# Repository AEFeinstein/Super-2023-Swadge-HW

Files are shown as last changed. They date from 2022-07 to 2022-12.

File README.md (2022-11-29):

# Super Magfest 2023 Swadge Hardware

## Welcome

This is the hardware repository for the Super Magfest 2022 Swadge.

The corresponding firmware repository for the Super Magfest 2023 Swadge [can be found here](https://github.com/AEFeinstein/Super-2023-Swadge-FW).

If you have any questions, feel free to create a Github ticket or email us at circuitboards@magfest.org.

## Render
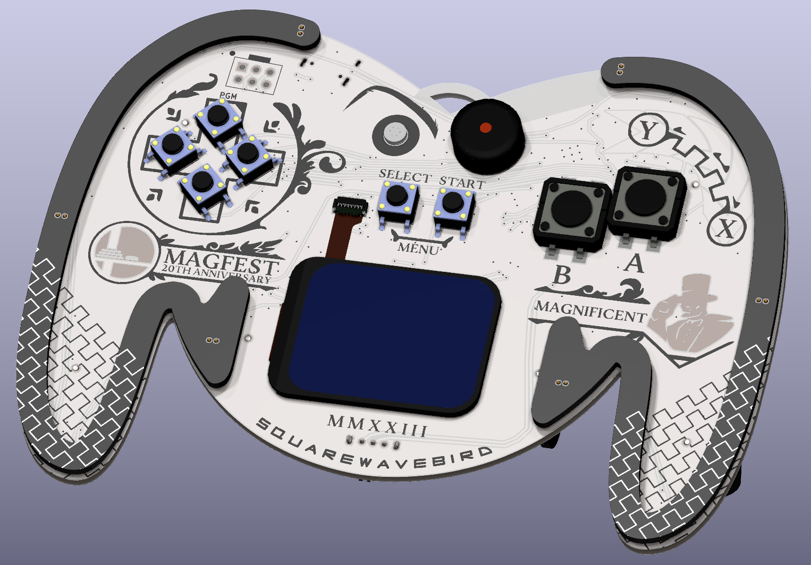
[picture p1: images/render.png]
Render


## Schematic

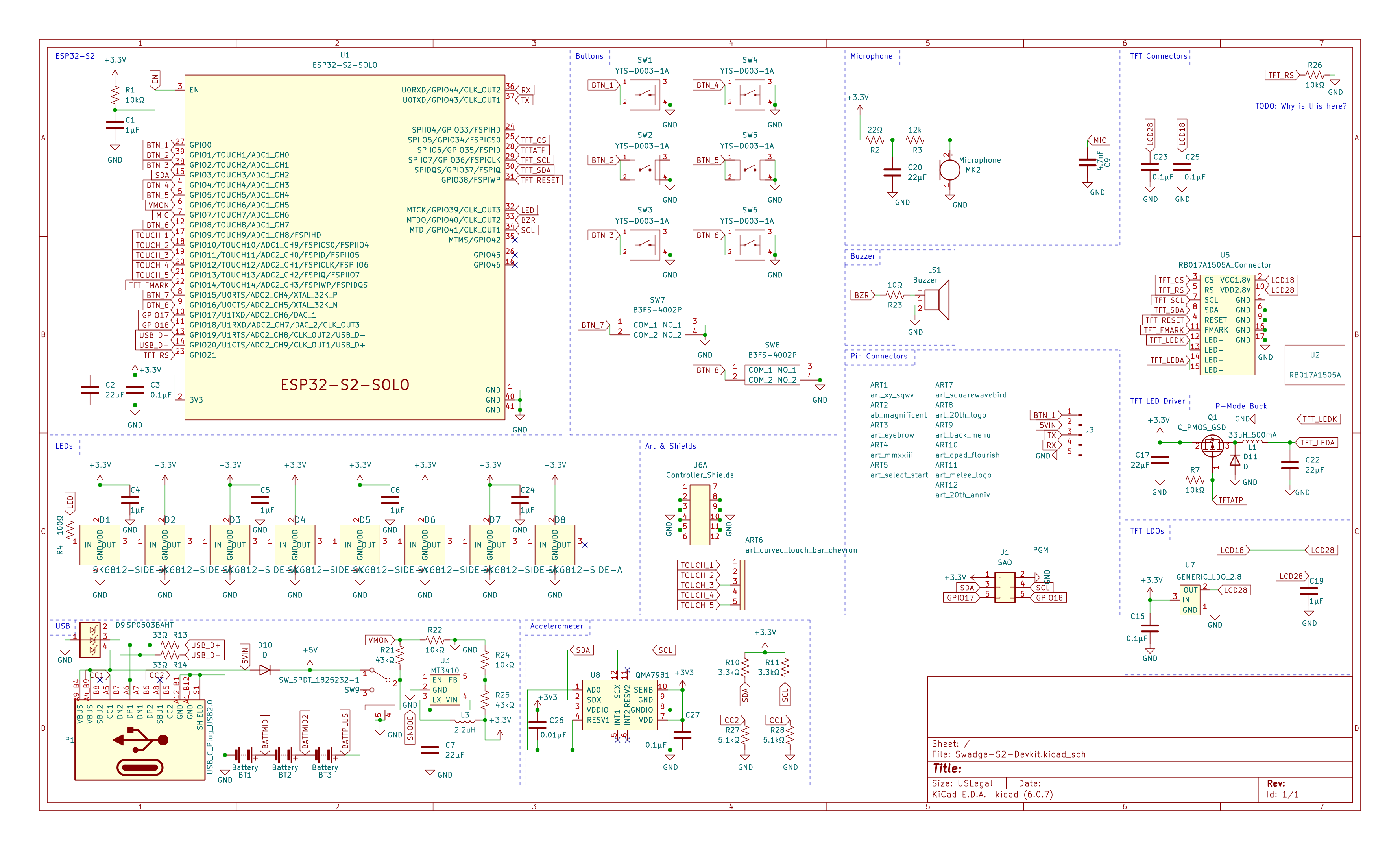
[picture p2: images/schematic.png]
Schematic


## Directories

### `art`
This directory has the SVGs used to generate the KiCad files. The SVGs are drawn in [Inkscape](https://inkscape.org/) and exported with [Svg2Shenzhen](https://github.com/badgeek/svg2shenzhen)
### `3D-Print`
This directory has the 3D print files for the Swadge "Eggshell". 
### `SAOs/SAO1`
This directory has the design files for a Simple Add On shaped like Lil'B
### `shield`
This directory has the KiCad project for the PCB shield which protects the LEDs. 
### `shield_l`
This directory has the KiCad project for a test left-side shield which protects the LEDs. It was never manufacturered.
### `shield_r`
This directory has the KiCad project for a test right-side shield which protects the LEDs. It was never manufacturered.
### `Swadge-Parts`
This directory is a git submodule which has all the parts, footprints, and 3D models used in this project.
### `Swadge-S2-Devkit`
This directory has the KiCad project for the main Swadge PCB. It's not really a devkit anymore, but it started out as one!

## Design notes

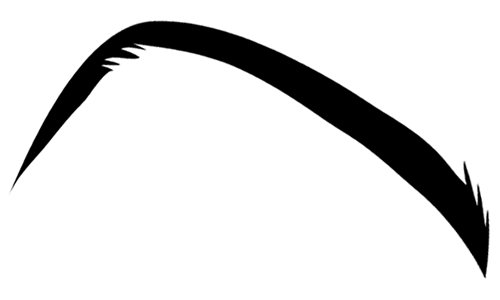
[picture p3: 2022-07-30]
art/Eyebrow.png

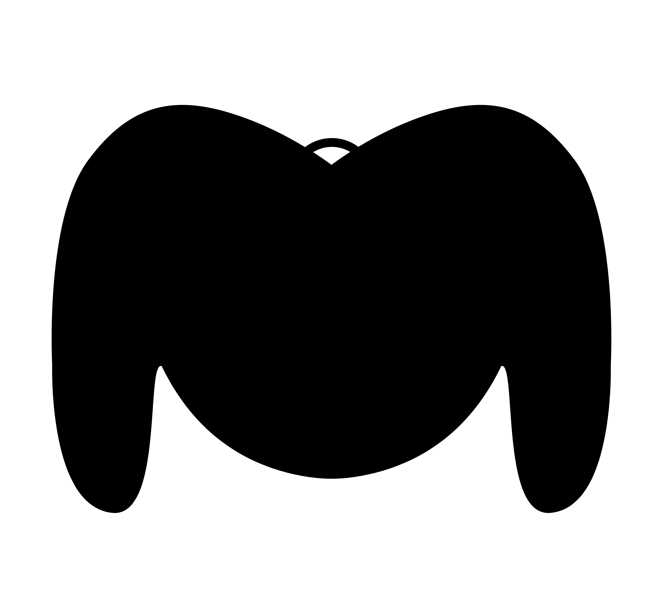
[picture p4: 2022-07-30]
art/Controller_Shape.png

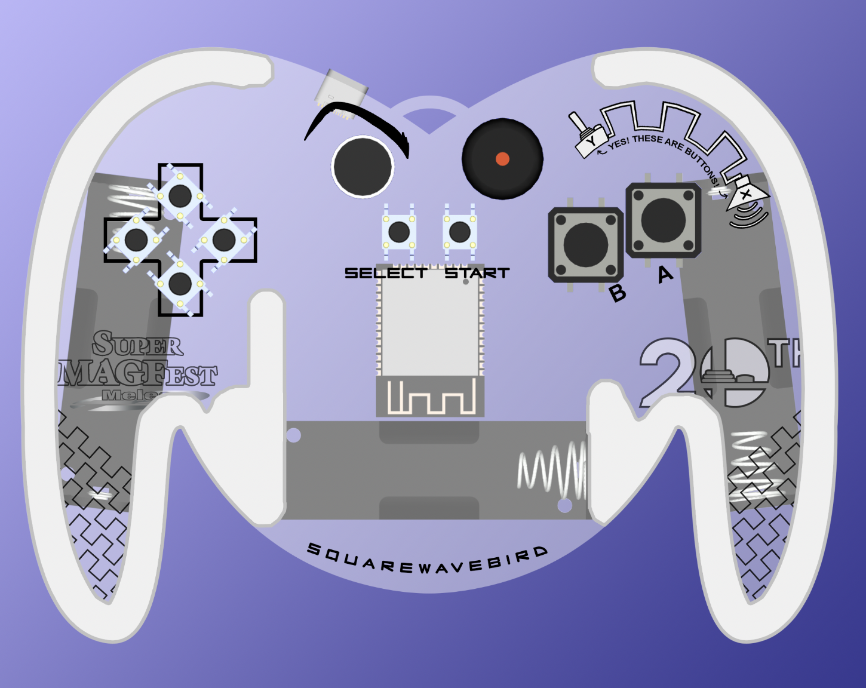
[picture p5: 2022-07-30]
art/_Dac_s Raster.png

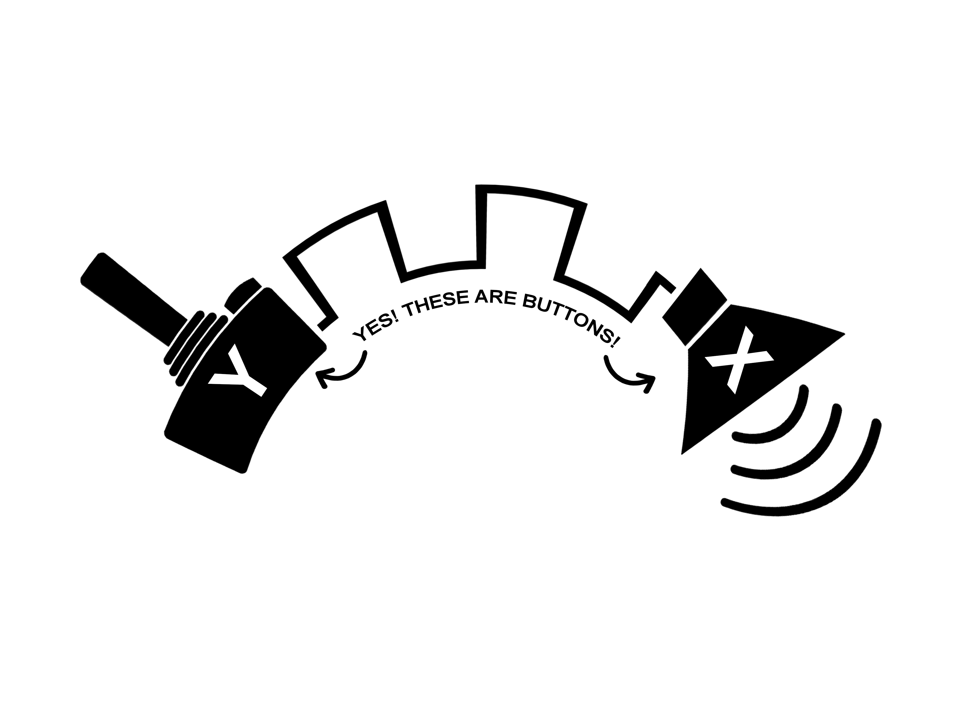
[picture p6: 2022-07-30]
art/XY_Buttons.png

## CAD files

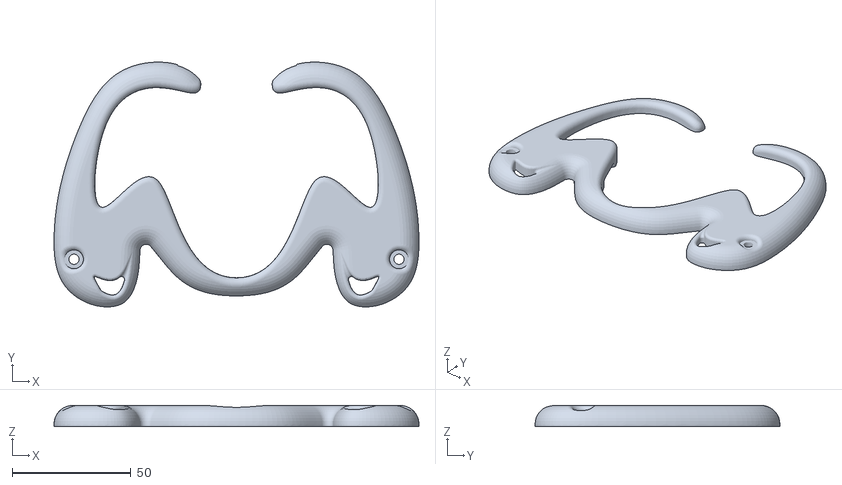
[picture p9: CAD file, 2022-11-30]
3D-Print/FDM/Eggshell_front_FDM.STL
153.4 x 102.9 x 8.89

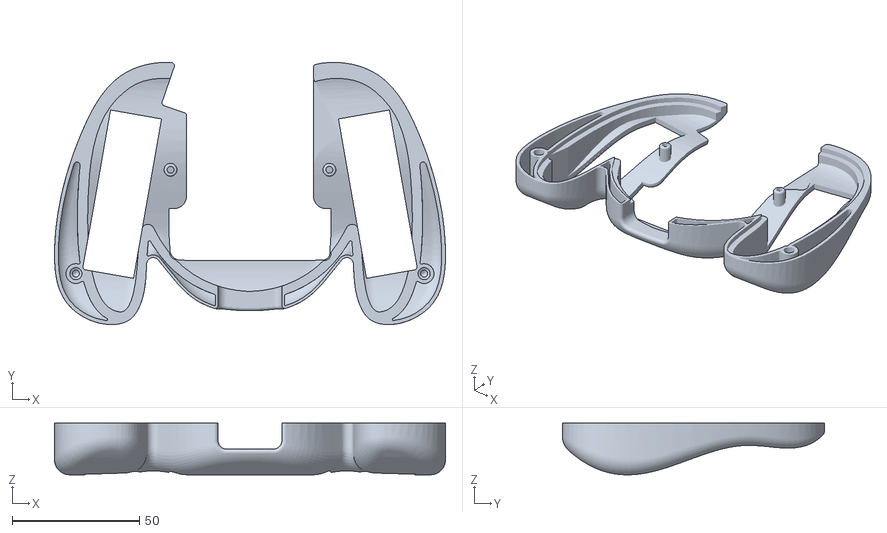
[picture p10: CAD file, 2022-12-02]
3D-Print/SLA/Eggshell_back_SLA.STL
153.4 x 102.9 x 20.3

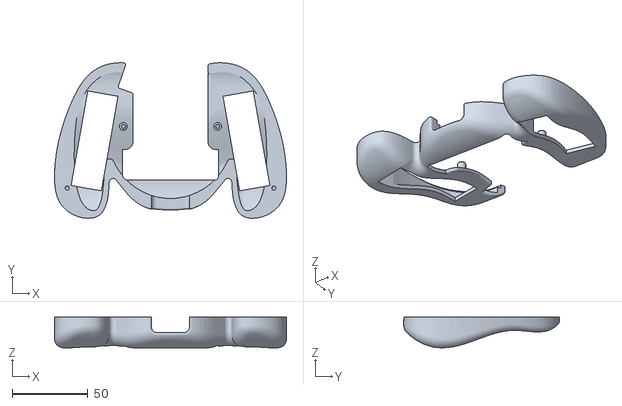
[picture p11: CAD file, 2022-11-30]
3D-Print/FDM/Eggshell_back_FDM.STL
153.4 x 102.9 x 20.3

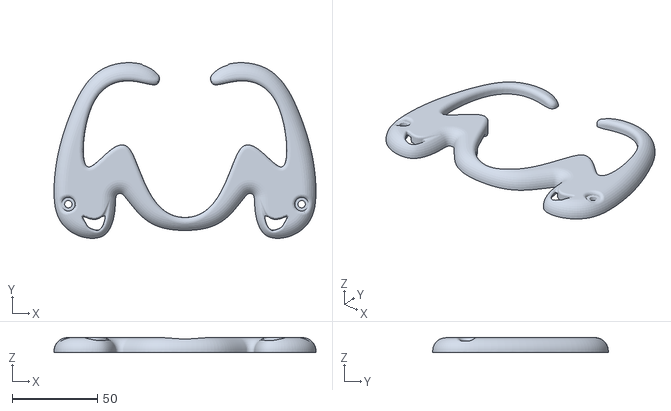
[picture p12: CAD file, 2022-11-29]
3D-Print/SLA/Eggshell_front_SLA.STL
153.4 x 102.9 x 8.69

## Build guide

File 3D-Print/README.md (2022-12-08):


<!--
*** Thanks for checking out the Best-README-Template. If you have a suggestion
*** that would make this better, please fork the repo and create a pull request
*** or simply open an issue with the tag "enhancement".
*** Don't forget to give the project a star!
*** Thanks again! Now go create something AMAZING! :D
-->

<!-- PROJECT SHIELDS -->
<!--
*** I'm using markdown "reference style" links for readability.
*** Reference links are enclosed in brackets [ ] instead of parentheses ( ).
*** See the bottom of this document for the declaration of the reference variables
*** for contributors-url, forks-url, etc. This is an optional, concise syntax you may use.
*** https://www.markdownguide.org/basic-syntax/#reference-style-links
-->

<!-- PROJECT LOGO -->
<br />
   
  <h1 align="center">Project Eggshell</h1>

  <p align="center">
    An ergonomic case for the 2023 Swadge
</p>

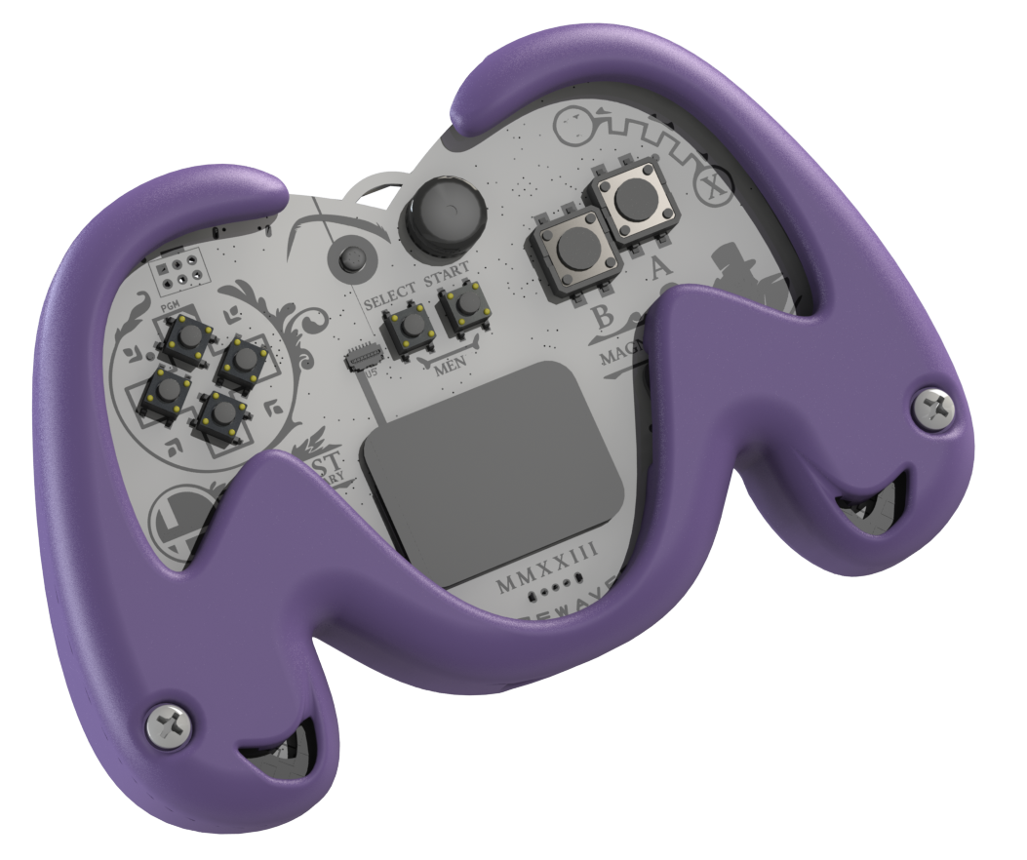
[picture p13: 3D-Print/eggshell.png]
Eggshell Render


### Built With
<br />

* [SOLIDWORKS 2020](https://www.solidworks.com) 

<p align="right">(<a href="#top">back to top</a>)</p>

<!-- GETTING STARTED -->
## Getting Started
<br />

Identify which type of printing technology you’d like to use to replicate your Swadge eggshell and use the respective files for that folder. It’s sincerely not recommended to use SLA files for FDM printers, though you could go the other way with significant resin use. This print has not been tested with SLS. 
<br />

### Materials

Materials required vary based on your printing method.

The materials used for the Eggshells produced for Super MAGFest 2023 are provided at the links below:

* <a href="https://www.amazon.com/Polymaker-Filament-1-75mm-Resistant-Cardboard/dp/B09DKQ7W32"> Purple ABS </a>

* <a href="https://www.amazon.com/dp/B08SQTR1FV">ClearPurple Resin</a> 

You’ll also need:

An FDM 3D printer capable of printing ABS filament with a minimum build volume of 150mm x 55mm x 20mm. Each piece was printed grip side UP and laid flat on the build plate. The eggshell was designed to minimize excess support structure. 15% infill should be plenty.

OR

An SLA printer capable of printing clear UV resin with a minimum build volume of 150mm x 55mm x 20mm. This has been tested on an Anycubic Photon Mono X for SLA prints with the following settings:

* Burn in layers: 6
* Burn in time: 35s
* Layer time: 3.2s
* UV power: 100%

Each side of the eggshell was printed individually at a 45deg angle based on True Elite Geek’s formula for resin printing. The grip surfaces were the supported side and gently sanded with 150 grit sandpaper post-printing, and then clear coated for finish.

OR

<p align="left">Money to spend at www.HUBS.com or www.shapeways.com to outsource prints.</p>

### Assembly

FDM and SLA prints are assembled differently. IF you are using a tappable resin such as Siraya Tech Build, you may be able to use the FDM mounting hardware. YMMV.

FDM Fasteners:

Any #6 x 5/8" self tapping screw. The eggshells were delivered at MAGFest 2023 with these screws: 
* Screws: https://www.mcmaster.com/92470A150/

SLA Fasteners:

The clear purple resin is not tappable. Use a press fit insert and a 6-32 x 1/2" screw instead. The eggshells were delivered at MAGFest 2023 with these fasteners:
* Threaded inserts: https://www.mcmaster.com/92395A113/
* Screws: https://www.mcmaster.com/91772A146/
 
<p align="right">(<a href="#top">back to top</a>)</p>

<!-- CONTRIBUTING -->
## Contributing

Contributions are what make the open-source community such an amazing place to learn, inspire, and create. Any contributions you make are **greatly appreciated**.

If you have a suggestion that would make this better, please fork the repo and create a pull request. You can also simply open an issue with the tag "enhancement".
Don't forget to give the project a star! Thanks again!

1. Fork the Project
2. Create your Feature Branch (`git checkout -b feature/AmazingFeature`)
3. Commit your Changes (`git commit -m 'Add some AmazingFeature'`)
4. Push to the Branch (`git push origin feature/AmazingFeature`)
5. Open a Pull Request

<p align="right">(<a href="#top">back to top</a>)</p>

<!-- LICENSE -->
## License

<p xmlns:cc="http://creativecommons.org/ns#" xmlns:dct="http://purl.org/dc/terms/"><a property="dct:title" rel="cc:attributionURL" href="https://github.com/AEFeinstein/Super-2023-Swadge-HW/tree/main/3D-Print">Swadge Eggshell</a> by <a rel="cc:attributionURL dct:creator" property="cc:attributionName" href="https://github.com/emilyanthony4244">Emily Anthony</a> is licensed under <a href="http://creativecommons.org/licenses/by-nc-sa/4.0/?ref=chooser-v1" target="_blank" rel="license noopener noreferrer" style="display:inline-block;">CC BY-NC-SA 4.0</a></p>

<!-- CONTACT -->
## Contact

Emily Anthony - [@thelegendofemily](https://instagram.com/thelegendofemily) 

Justin Gohlke –
[@justintroubleagain]( https://www.instagram.com/justintroubleagain/)

Project Link: https://github.com/AEFeinstein/Super-2023-Swadge-HW/

<p align="right">(<a href="#top">back to top</a>)</p>

<!-- ACKNOWLEDGMENTS -->
## Acknowledgments

* Justin Gohlke aka Eggman for being the mad scientist and dedicated printer for this project
* The Swadge team for idea generation, continuous feedback, and general tolerance for Justin and Emily to go buckwild
* MAGFest volunteers and employees for their overwhelming support and willingness to help push this side project
* [OthNealDrew’s Readme template]( https://github.com/othneildrew/Best-README-Template)

<p align="right">(<a href="#top">back to top</a>)</p>

<!-- MARKDOWN LINKS & IMAGES -->
<!-- https://www.markdownguide.org/basic-syntax/#reference-style-links -->
[contributors-shield]: https://img.shields.io/github/contributors/emilyanthony4244/Sheikah_Slate.svg?style=for-the-badge
[contributors-url]: 
https://github.com/AEFeinstein/Super-2023-Swadge-HW/graphs/contributors
[linkedin-shield]: https://img.shields.io/badge/-LinkedIn-black.svg?style=for-the-badge&logo=linkedin&colorB=555
[linkedin-url]: https://linkedin.com/in/emilyanthony

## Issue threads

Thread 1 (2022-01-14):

Validate Schematic

AEFeinstein, 2022-01-14:
Blocks to validate:
- [x] ESP32-S2
- [x] Buttons
- [x] Microphone
- [x] Speaker
- [x] Buzzer
- [x] TFT Display
- [x] LEDs
- [x] Vibration Motor
- [x] Edge Connector
- [x] Pin Headers
- [x] Accelerometer
- [x] USB
- [x] Touch Sensor

Closed 2022-09-02.

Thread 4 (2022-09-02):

Prototype Feedback

AEFeinstein, 2022-09-02:
# Silkscreen
 - [x] Replace chevron silkscreen with X/Y silkscreen
 - [x] Add silkscreen for power switch sides
 - [x] Add URL silkscreen "swadge.com/super2023/"
 - [x] Add e-mail silkscreen circuitboards@magfest.org
 - [x] Add version silkscreen (1.0.1)
 - [x] Add A and B button silkscreen
 - [x] Add silkscreen dot or marking or something for UP on the D-Pad to indicate "programming mode button"
 - [x] "Yes these are buttons"

# LEDs
 - [ ] Fix LED placement
 - [ ] Swap LED types

# Kidneys
 - [x] Enlarge holes for kidney mounting. reimport footprint for both main part and PCB
 - [x] Tie all kidney mounting holes to GND, not VCC.
 - [ ] Decide shield location
 - [ ] Either use a thicker kidney (1.6mm) or add another mounting point at the bottom of the controller grip
 - [ ] Pick a kidney!

# Part Placement
 - [x] Move SAO out from under kidney, flip to front of Swadge
 - [x] Rotate start/select 90 degrees, push closer together, move TFT upwards
 - [x] Update TFT part to accommodate either long or short tail, just in case (@cnlohr to email Ronbo)
 - [x] Move power switch up to not hang over the board so much (flush)

# Misc
 - [x] Remove UART pads (nah, let's leave them)
 - [x] Pick a microphone, scrap the other, move it to original location (@cnlohr, you get to pick. My preference is for the larger one to balance the buzzer)
 - [x] Mic pullup needs to be 10k
 - [x] R3 needs to be 10k
 - [x] Remove or shrink button debounce caps
 - [x] Add CC1/CC2 pullups for USB-C power

# BOM
 - [x] Use low-force buttons for A/B (https://lcsc.com/product-detail/Tactile-Switches_XKB-Connectivity-TS-1103S-B-A_C2929546.html is the best I could find)
 - [x] DNP the SAO.
 - [x] R5 has wrong LCSC part #

AEFeinstein, 2022-09-02:
@cnlohr, as far as division of labor, I would prefer if you update the mic components & BOM stuff. I can do the silkscreen and part placement (and probably the rerouting too)

cnlohr, 2022-09-03:
[ ] SAO movement.
[ ] Make Switch flush with board.

cnlohr, 2022-09-03:
- [ ] Move microphone to where old mic was.

cnlohr, 2022-09-03:
- [ ] Try to make the switch go right up next to the USB.

AEFeinstein, 2022-09-04:
> SAO movement.
"Move SAO out from under kidney, flip to front of Swadge" in the ticket description

> Make Switch flush with board.
"Move power switch up to not hang over the board so much (flush)" in the ticket description

> Move microphone to where old mic was.
"Pick a microphone, scrap the other, move it to original location" in the ticket description

> Try to make the switch go right up next to the USB.
Was this feedback from the jam?

cnlohr, 2022-09-05:
Only thing I think I need to answer is that yes, switch up was feedback from jam.  @AEFeinstein are you OK with that?  Looks like you already fixed it. You did fix it right?  I'm not crazy?

Closed 2022-09-06.

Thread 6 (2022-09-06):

Fix SW9 silkscreen + Move ring

cnlohr, 2022-09-06:
Says in title.

This is post EV2

AEFeinstein, 2022-09-06:
What's wrong with SW9? BT1 needs to be reset to have (-) be aligned

cnlohr, 2022-09-06:
Aaah ok

Plx assign to me.  I have the semaphore.  I am currently balancing both branches. I'd rather not make mods until the orders are in.

AEFeinstein, 2022-09-06:
Reassigned. Have fun balancing the branches. Kicad files aren't that git friendly 😟

As a general note, when you're done with branches (either merged or abandoned), remember to delete them!

cnlohr, 2022-09-21:
SW9 was resolved at some point..
Ring looks "too low" based on screen silk.

<div style="font-family:Verdana,Geneva,sans-serif"><span class="im">
<p>Dear Charles,</p>
<p>Thanks for your feedback!</p>
</span><p>I understand the situation of your production prototypes, sorry for your confuse!</p>
<p>I will provide the old ones (yellow) which are measured to be 32mm,</p>
<p>please design your production prototypes according to this 32mm length,</p><span class="im">
<p>Have a nice day!</p></span></div></div></div></div>

AEFeinstein, 2022-09-21:
> SW9 was resolved at some point.

OK, I'm not going crazy

> Ring looks "too low" based on screen silk.

I fixed that in the `more-cad` branch when doing Dac's render. PR here: https://github.com/AEFeinstein/Swadge-S2-Devkit/pull/7

Closed 2022-10-30.

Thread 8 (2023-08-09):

Need replacement LCD

camprevail, 2023-08-09:
Hi, I cracked my 2023 swadge LCD and I searched through this repo but I can't find the LCD model used so I can replace it. Can you help me out?

AEFeinstein, 2023-08-09:
The info is buried in the BOM in the release zip, but it's a RB017A1505A from http://www.ronboe.com/ or https://ronboelectronics.en.made-in-china.com/ (I'm not sure why they have two websites). The part isn't listed, but if you email you may be able to get a sample. We bought a large quantity and I'm not sure how they feel about single orders.

Closed 2023-08-09.

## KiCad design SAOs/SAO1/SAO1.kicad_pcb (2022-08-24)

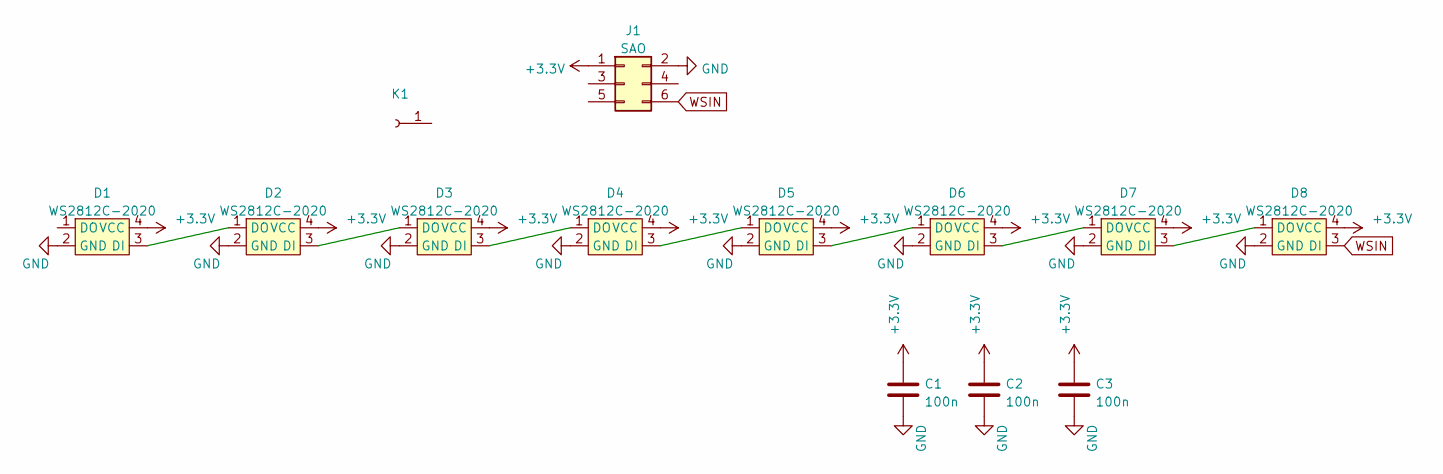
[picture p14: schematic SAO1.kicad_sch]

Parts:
C1, C2, C3: 100n; C_0603_1608Metric; LCSC C14663
D1, D2, D3, D4, D5, D6, D7, D8: WS2812C-2020; LCSC C2976072
J1: SAO; PinHeader_2x03_P2.54mm_Vertical; LCSC C65114
K1: bananaraptor

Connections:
+3.3V: C1.1, C2.1, C3.1, D1.4 (VCC), D2.4 (VCC), D3.4 (VCC), D4.4 (VCC), D5.4 (VCC), D6.4 (VCC), D7.4 (VCC), D8.4 (VCC), J1.1
GND: C1.2, C2.2, C3.2, D1.2 (GND), D2.2 (GND), D3.2 (GND), D4.2 (GND), D5.2 (GND), D6.2 (GND), D7.2 (GND), D8.2 (GND), J1.2
unnamed: D1.3 (DI), D2.1 (DO)
unnamed: D2.3 (DI), D3.1 (DO)
unnamed: D3.3 (DI), D4.1 (DO)
unnamed: D4.3 (DI), D5.1 (DO)
unnamed: D5.3 (DI), D6.1 (DO)
unnamed: D6.3 (DI), D7.1 (DO)
unnamed: D7.3 (DI), D8.1 (DO)
WSIN: D8.3 (DI), J1.6

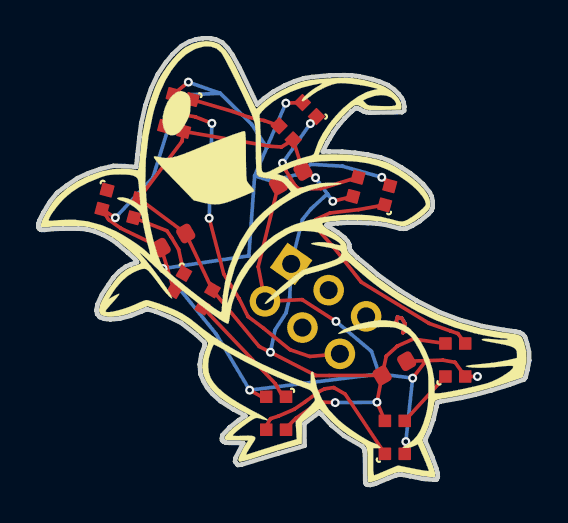
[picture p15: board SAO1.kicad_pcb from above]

Board: 2 copper layers, 27.3 x 24.8 mm, 13 parts (1 on the bottom side), 10 nets.

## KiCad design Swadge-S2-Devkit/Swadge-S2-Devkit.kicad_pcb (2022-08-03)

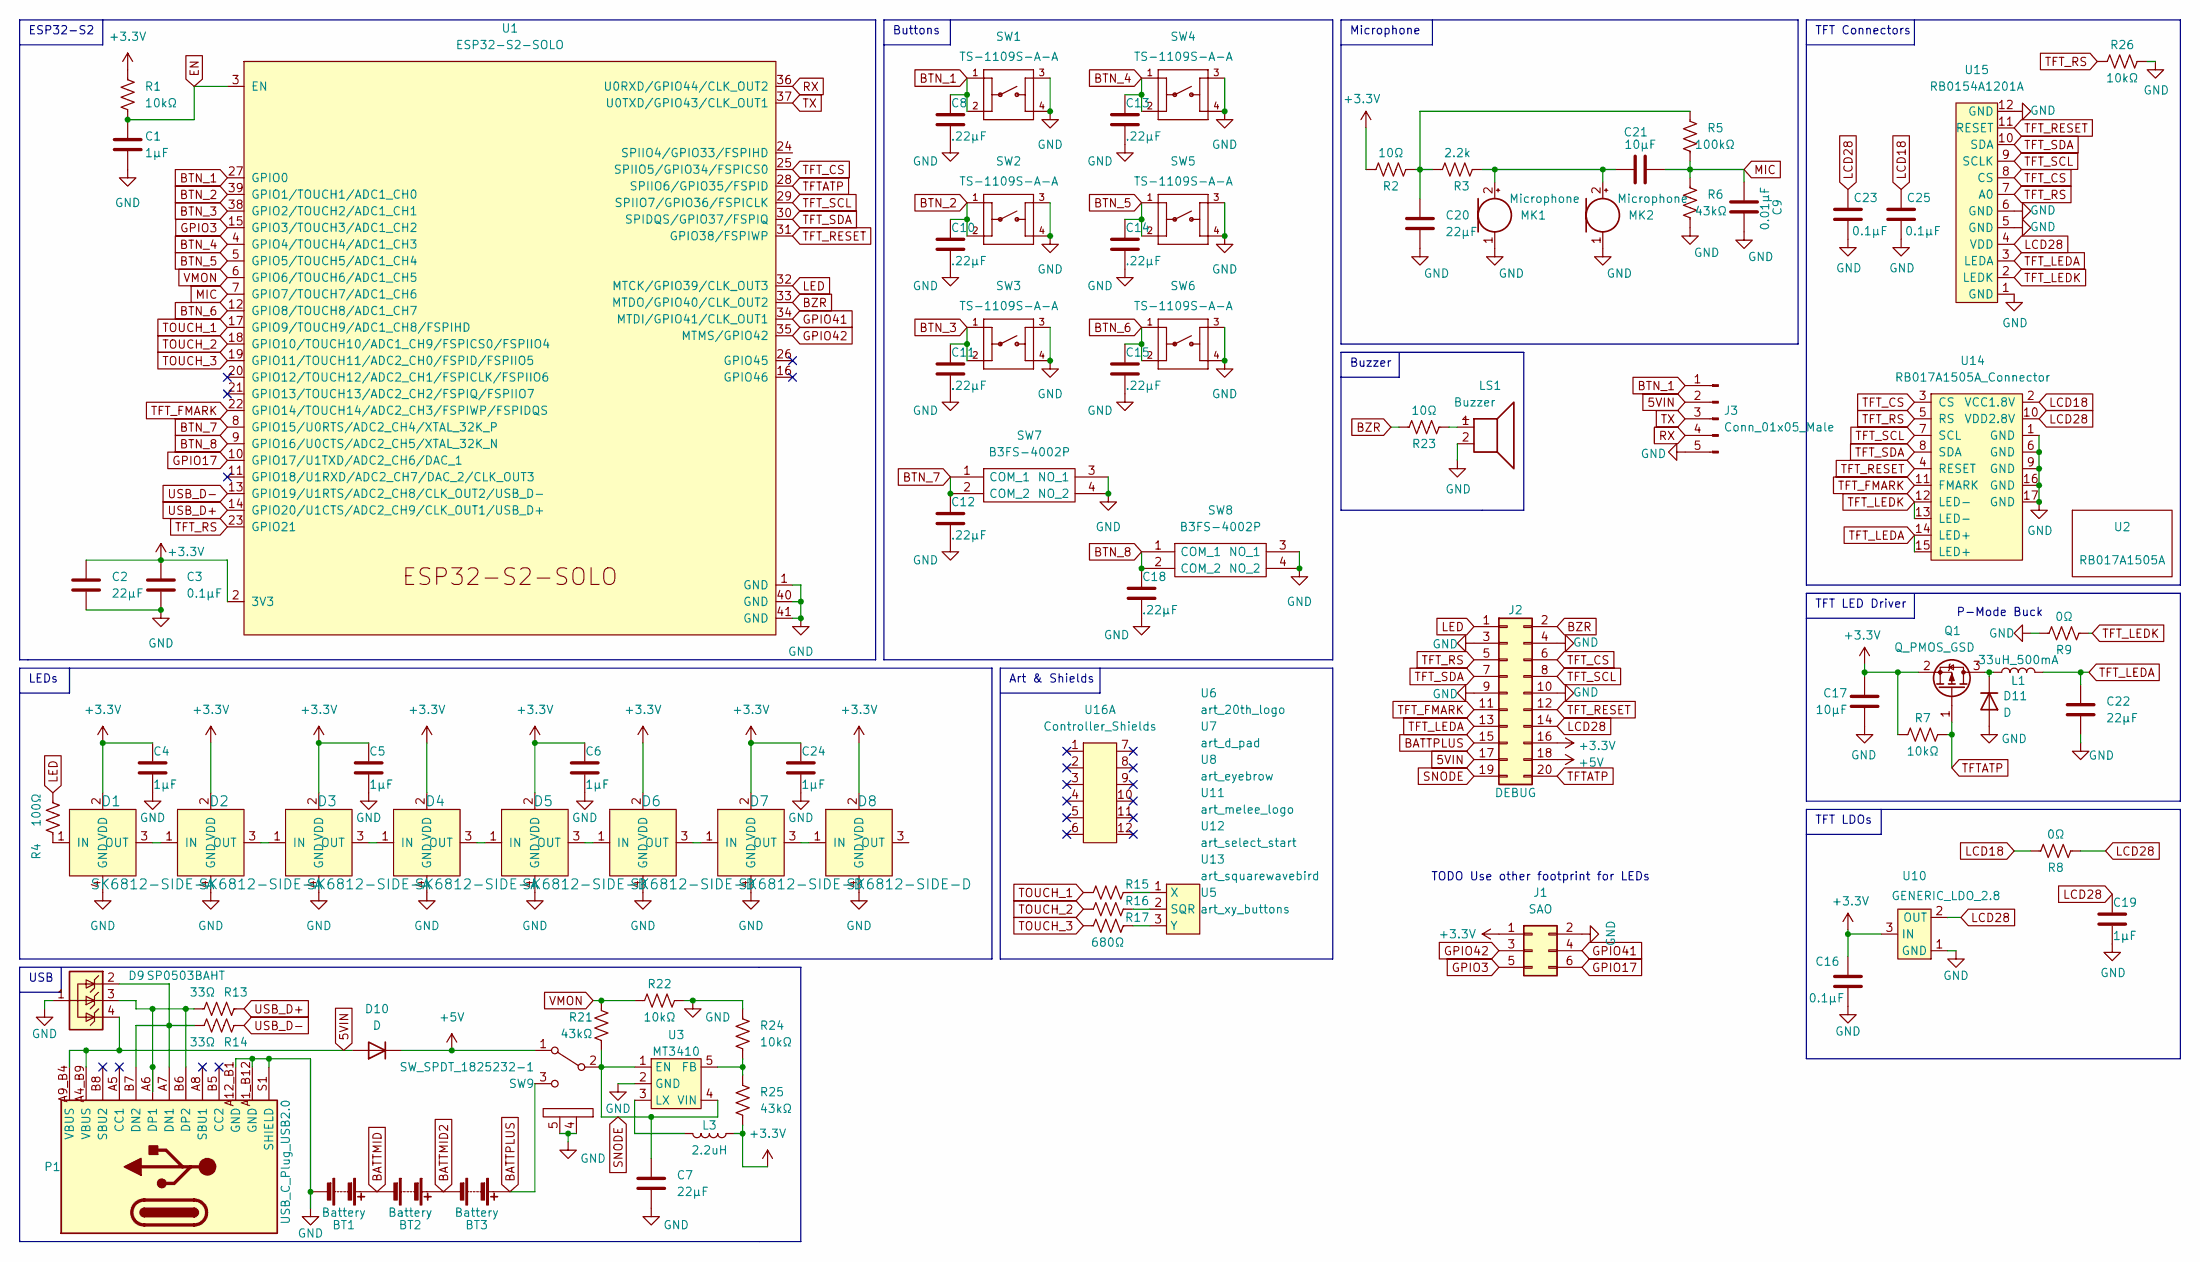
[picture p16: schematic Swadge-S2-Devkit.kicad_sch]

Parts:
BT1, BT2, BT3: Battery; 2460; Digikey 36-2460-ND
C1, C4, C5, C6, C19, C24: 1μF; C_0603_1608Metric; LCSC C1592
C2, C7, C20, C22: 22μF; C_0603_1608Metric; LCSC C86295
C3, C16, C23, C25: 0.1μF; C_0603_1608Metric; LCSC C282519
C8, C10, C11, C12, C13, C14, C15, C18: .22μF; C_0603_1608Metric; LCSC C21120
C9: 0.01μF; C_0603_1608Metric; LCSC C14663
C17, C21: 10μF; C_0603_1608Metric; LCSC C96446
D1, D2, D3, D4: SK6812-SIDE-A; SK6812_SIDE_2; Digikey 1528-4691-ND
D5, D6, D7, D8: SK6812-SIDE-D; SK6812D_SIDE; Digikey 2007-BB-HRGB24R-TRB-BTR-ND
D9: SP0503BAHT; SOT-143; Digikey F2715CT-ND
D10, D11: D; D_SMA; Digikey 2616-GS1J-ND
J1: SAO; PinSocket_2x03_P2.54mm_Vertical; LCSC N/A
J2: DEBUG; PinHeader_2x10_P2.54mm_Vertical; LCSC C492427
J3: Conn_01x05_Male; PinHeader_1x05_P2.54mm_Vertical; LCSC C390683
L1: 33uH_500mA; L_1210_3225Metric; LCSC C90317
L3: 2.2uH; L_1008_2520Metric; LCSC C216158
LS1: Buzzer; Buzzer_12.5x7.5; LCSC C219727
MK1: Microphone; INGHAi GMI6050P-56DB; Digikey 102-1721-ND
MK2: Microphone; GOERTEK_MIC_B4013AM423; LCSC C2835889
P1: USB_C_Plug_USB2.0; USB_C_Receptacle_HRO_TYPE-C-31-M-12; LCSC C2765186
Q1: Q_PMOS_GSD; SOT-23; LCSC C2763847
R1, R7, R22, R24, R26: 10kΩ; R_0603_1608Metric; LCSC C25197
R2, R23: 10Ω; R_0603_1608Metric; LCSC C22859
R3: 2.2k; R_0603_1608Metric; LCSC C4190
R4: 100Ω; R_0603_1608Metric; LCSC C22936
R5: 100kΩ; R_0603_1608Metric; LCSC C22936
R6, R21, R25: 43kΩ; R_0603_1608Metric; LCSC C23172
R8, R9: 0Ω; R_0603_1608Metric; LCSC C21189
R13, R14: 33Ω; R_0603_1608Metric; LCSC C23140
R15, R16, R17: 680Ω; R_0603_1608Metric; LCSC C23228
SW1, SW2, SW3, SW4, SW5, SW6: TS-1109S-A-A; SW_4-1437565-2; Digikey 2223-TS04-66-65-BK-100-SMT-ND
SW7, SW8: B3FS-4002P; B3FS4002P; Digikey SW1278CT-ND
SW9: SW_SPDT_1825232-1; 1825232-1; Digikey A107673-ND
U1: ESP32-S2-SOLO; Digikey 1965-ESP32-S2-SOLO-N4R2TR-ND
U2: RB017A1505A; NULL
U3: MT3410; SOT-23-5; LCSC C883494
U5: art_xy_buttons; XY_Buttons
U6: art_20th_logo; 20th_Logo
U7: art_d_pad; d-pad
U8: art_eyebrow; eyebrow
U10: GENERIC_LDO_2.8; SOT-23; LCSC C347374
U11: art_melee_logo; Melee_Logo
U12: art_select_start; select-start
U13: art_squarewavebird; squarewavebird
U14: RB017A1505A_Connector; HCTL HC-FPC-03-10-15RLTAG; Digikey A141392TR-ND
U15: RB0154A1201A; LCD_240x240_1.54_12
U16: Controller_Shields; shields; LCSC C124375

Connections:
5VIN: D9.4 (K), D10.2 (A), J2.17, J3.2, P1.A4_B9 (VBUS), P1.A9_B4 (VBUS)
+3V3: C2.1, C3.1, C4.1, C5.1, C6.1, C16.1, C17.1, C24.1, D1.2 (VDD), D2.2 (VDD), D3.2 (VDD), D4.2 (VDD), D5.2 (VDD), D6.2 (VDD), D7.2 (VDD), D8.2 (VDD), J1.1, J2.16, L3.1, Q1.2 (S), R1.1, R2.1, R7.1, R25.2, U1.2 (3V3), U10.3 (IN)
+5V: D10.1 (K), J2.18, SW9.1 (A)
BATTMID: BT1.1 (+), BT2.2 (-)
BATTMID2: BT2.1 (+), BT3.2 (-)
BATTPLUS: BT3.1 (+), J2.15, SW9.3 (C)
BTN_1: C8.1, J3.1, SW1.1, SW1.2, U1.27 (GPIO0)
BTN_2: C10.1, SW2.1, SW2.2, U1.39 (GPIO1/TOUCH1/ADC1_CH0)
BTN_3: C11.1, SW3.1, SW3.2, U1.38 (GPIO2/TOUCH2/ADC1_CH1)
BTN_4: C13.1, SW4.1, SW4.2, U1.4 (GPIO4/TOUCH4/ADC1_CH3)
BTN_5: C14.1, SW5.1, SW5.2, U1.5 (GPIO5/TOUCH5/ADC1_CH4)
BTN_6: C15.1, SW6.1, SW6.2, U1.12 (GPIO8/TOUCH8/ADC1_CH7)
BTN_7: C12.1, SW7.1 (COM_1), SW7.2 (COM_2), U1.8 (GPIO15/U0RTS/ADC2_CH4/XTAL_32K_P)
BTN_8: C18.1, SW8.1 (COM_1), SW8.2 (COM_2), U1.9 (GPIO16/U0CTS/ADC2_CH5/XTAL_32K_N)
BZR: J2.2, R23.1, U1.33 (MTDO/GPIO40/CLK_OUT2)
EN: C1.1, R1.2, U1.3 (EN)
GND: BT1.2 (-), C1.2, C2.2, C3.2, C4.2, C5.2, C6.2, C7.2, C8.2, C9.1, C10.2, C11.2, C12.2, C13.2, C14.2, C15.2, C16.2, C17.2, C18.2, C19.2, C20.2, C22.2, C23.2, C24.2, C25.2, D1.4 (GND), D2.4 (GND), D3.4 (GND), D4.4 (GND), D5.4 (GND), D6.4 (GND), D7.4 (GND), D8.4 (GND), D9.1 (A), D11.2 (A), J1.2, J2.3, J2.4, J2.9, J2.10, J3.5, LS1.2, MK1.1 (-), MK2.1 (-), P1.A1_B12 (GND), P1.A12_B1 (GND), P1.S1 (SHIELD), R6.2, R9.1, R22.2, R24.1, R26.2, SW1.3, SW1.4, SW2.3, SW2.4, SW3.3, SW3.4, SW4.3, SW4.4, SW5.3, SW5.4, SW6.3, SW6.4, SW7.3 (NO_1), SW7.4 (NO_2), SW8.3 (NO_1), SW8.4 (NO_2), SW9.4 (D), SW9.5 (E), U1.1 (GND), U1.40 (GND), U1.41 (GND), U3.2 (GND), U10.1 (GND), U14.1 (GND), U14.6 (GND), U14.9 (GND), U14.16 (GND), U14.17 (GND), U15.1 (GND), U15.5 (GND), U15.6 (GND), U15.12 (GND)
GPIO3: J1.5, U1.15 (GPIO3/TOUCH3/ADC1_CH2)
GPIO17: J1.6, U1.10 (GPIO17/U1TXD/ADC2_CH6/DAC_1)
GPIO41: J1.4, U1.34 (MTDI/GPIO41/CLK_OUT1)
GPIO42: J1.3, U1.35 (MTMS/GPIO42)
LCD18: C25.1, R8.1, U14.2 (VCC1.8V)
LCD28: C19.1, C23.1, J2.14, R8.2, U10.2 (OUT), U14.10 (VDD2.8V), U15.4 (VDD)
LED: J2.1, R4.1, U1.32 (MTCK/GPIO39/CLK_OUT3)
MIC: C9.2, C21.2, R5.2, R6.1, U1.7 (GPIO7/TOUCH7/ADC1_CH6)
unnamed: C20.1, R2.2, R3.1, R5.1
unnamed: C21.1, MK1.2 (+), MK2.2 (+), R3.2
unnamed: D1.1 (IN), R4.2
unnamed: D1.3 (OUT), D2.1 (IN)
unnamed: D2.3 (OUT), D3.1 (IN)
unnamed: D3.3 (OUT), D4.1 (IN)
unnamed: D4.3 (OUT), D5.1 (IN)
unnamed: D5.3 (OUT), D6.1 (IN)
unnamed: D6.3 (OUT), D7.1 (IN)
unnamed: D7.3 (OUT), D8.1 (IN)
unnamed: D9.3 (K), P1.A6 (DP1), P1.B6 (DP2), R13.2
unnamed: D11.1 (K), L1.1, Q1.3 (D)
unnamed: L3.2, U3.3 (LX)
unnamed: LS1.1, R23.2
unnamed: D9.2 (K), P1.A7 (DN1), P1.B7 (DN2), R14.2
unnamed: R15.1, U5.1 (X)
unnamed: R16.1, U5.2 (SQR)
unnamed: R17.1, U5.3 (Y)
unnamed: R24.2, R25.1, U3.5 (FB)
RX: J3.4, U1.36 (U0RXD/GPIO44/CLK_OUT2)
SNODE: C7.1, J2.19, R21.2, SW9.2 (B), U3.1 (EN), U3.4 (VIN)
TFTATP: J2.20, Q1.1 (G), R7.2, U1.28 (SPIIO6/GPIO35/FSPID)
TFT_CS: J2.6, U1.25 (SPIIO5/GPIO34/FSPICS0), U14.3 (CS), U15.8 (CS)
TFT_FMARK: J2.11, U1.22 (GPIO14/TOUCH14/ADC2_CH3/FSPIWP/FSPIDQS), U14.11 (FMARK)
TFT_LEDA: C22.1, J2.13, L1.2, U14.14 (LED+), U14.15 (LED+), U15.3 (LEDA)
TFT_LEDK: R9.2, U14.12 (LED-), U14.13 (LED-), U15.2 (LEDK)
TFT_RESET: J2.12, U1.31 (GPIO38/FSPIWP), U14.4 (RESET), U15.11 (RESET)
TFT_RS: J2.5, R26.1, U1.23 (GPIO21), U14.5 (RS), U15.7 (A0)
TFT_SCL: J2.8, U1.29 (SPIIO7/GPIO36/FSPICLK), U14.7 (SCL), U15.9 (SCLK)
TFT_SDA: J2.7, U1.30 (SPIDQS/GPIO37/FSPIQ), U14.8 (SDA), U15.10 (SDA)
TOUCH_1: R15.2, U1.17 (GPIO9/TOUCH9/ADC1_CH8/FSPIHD)
TOUCH_2: R16.2, U1.18 (GPIO10/TOUCH10/ADC1_CH9/FSPICS0/FSPIIO4)
TOUCH_3: R17.2, U1.19 (GPIO11/TOUCH11/ADC2_CH0/FSPID/FSPIIO5)
TX: J3.3, U1.37 (U0TXD/GPIO43/CLK_OUT1)
USB_D+: R13.1, U1.14 (GPIO20/U1CTS/ADC2_CH9/CLK_OUT1/USB_D+)
USB_D-: R14.1, U1.13 (GPIO19/U1RTS/ADC2_CH8/CLK_OUT2/USB_D-)
VMON: R21.1, R22.1, U1.6 (GPIO6/TOUCH6/ADC1_CH5)

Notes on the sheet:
TFT LDOs
P-Mode Buck
Art & Shields
Buttons
ESP32-S2
Microphone
LEDs
TODO Use other footprint for LEDs
TFT LED Driver
TFT Connectors
USB
Buzzer

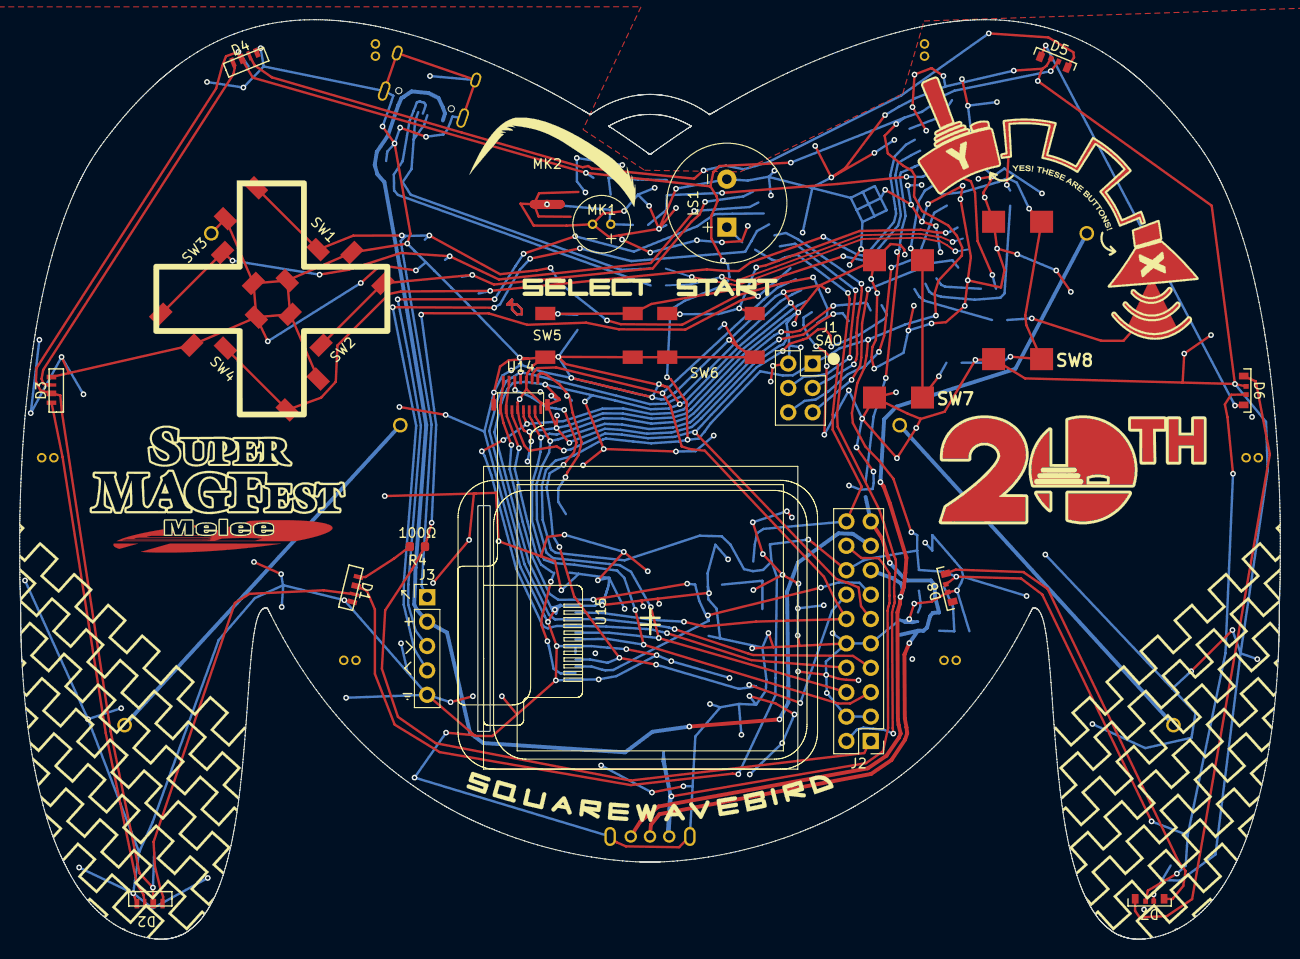
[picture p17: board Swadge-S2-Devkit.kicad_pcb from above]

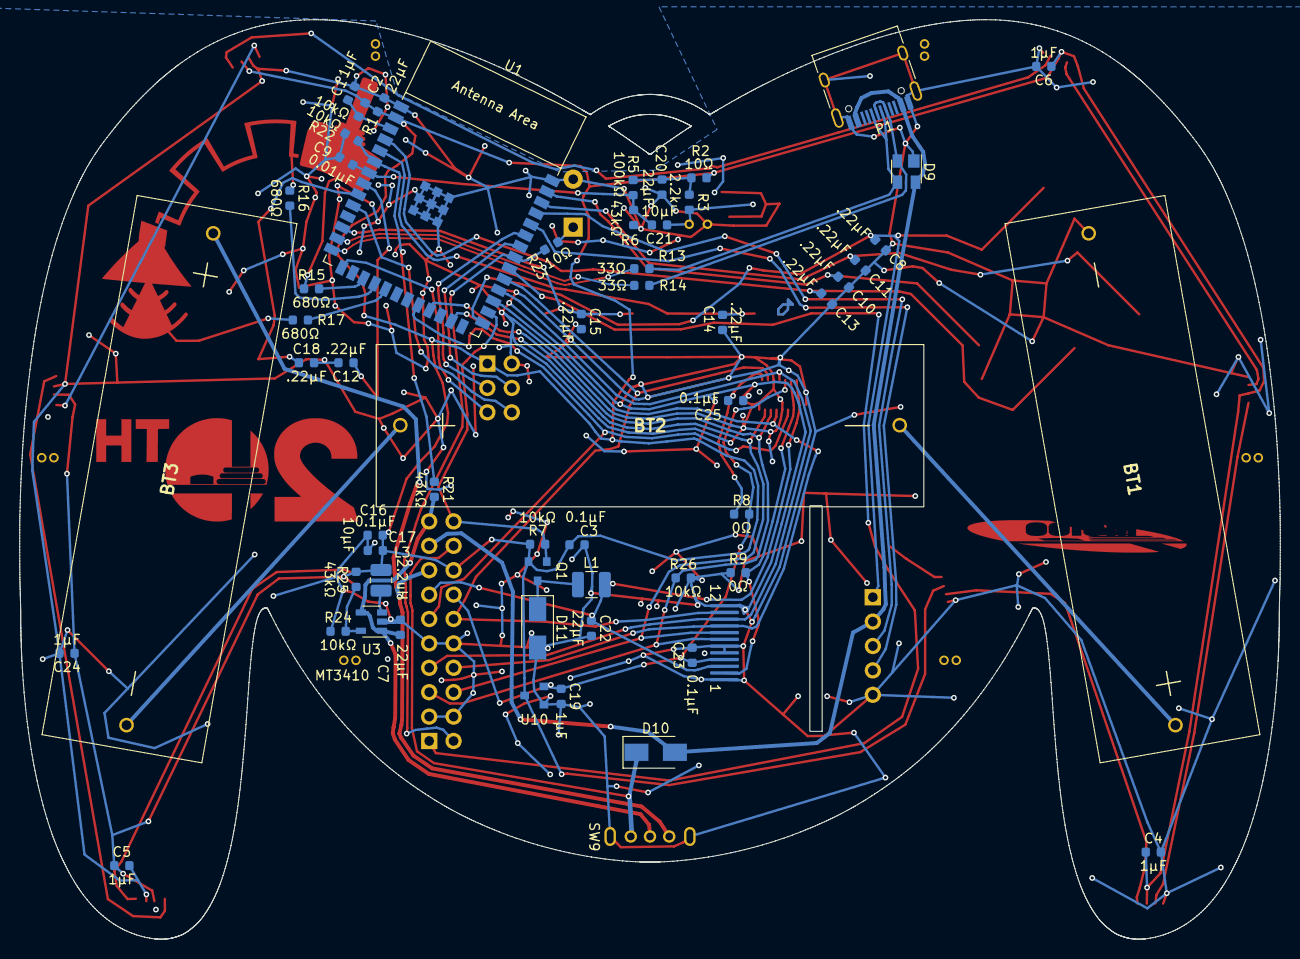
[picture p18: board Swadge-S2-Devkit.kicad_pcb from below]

Board: 2 copper layers, 131.2 x 95.7 mm, 93 parts (58 on the bottom side), 62 nets.

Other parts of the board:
Ref**: Val**; Controller_Shape

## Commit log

2021-12-27 Added project, swadge parts submodule
    [Swadge-S2-Devkit.kicad_pcb, Swadge-S2-Devkit.kicad_sch]
2021-12-27 Added ESP32 and board outline
    [Swadge-S2-Devkit.kicad_pcb, Swadge-S2-Devkit.kicad_sch]
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2022-01-02 Added more to schematic
    [Swadge-S2-Devkit.kicad_pcb, Swadge-S2-Devkit.kicad_sch]
2022-01-03 Added TFT, vib motor
    [Swadge-S2-Devkit.kicad_pcb, Swadge-S2-Devkit.kicad_sch]
2022-01-05 Updated layout
    [Swadge-S2-Devkit.kicad_pcb]
2022-01-06 Updated PCB
    [Swadge-S2-Devkit.kicad_pcb]
2022-01-13 Connected PCIe, replaced S3 with S2, cleanup
    [Swadge-S2-Devkit.kicad_pcb, Swadge-S2-Devkit.kicad_sch]
2022-01-14 Added diodes to USB, added pin headers, cleaned schematic
    [Swadge-S2-Devkit.kicad_pcb, Swadge-S2-Devkit.kicad_sch]
2022-01-14 Added missing label
    [Swadge-S2-Devkit.kicad_sch]
2022-01-14 Update peripherals and library.
    [Swadge-S2-Devkit.kicad_sch]
2022-01-19 Working on devkit, progress.
    [Swadge-S2-Devkit.kicad_pcb, Swadge-S2-Devkit.kicad_sch]
2022-01-19 Bump rev.
    [Swadge-S2-Devkit.kicad_pcb, Swadge-S2-Devkit.kicad_sch]
2022-01-20 Update with routing.
    [Swadge-S2-Devkit.kicad_pcb, Swadge-S2-Devkit.kicad_sch]
2022-01-22 Update design.
    [Swadge-S2-Devkit.kicad_pcb, Swadge-S2-Devkit.kicad_sch]
2022-01-28 bump schematic notes
    [Swadge-S2-Devkit.kicad_sch]
2022-04-04 Bump with design changes + devkit footprints
    [Swadge-S2-Devkit.kicad_sch]
2022-04-05 Update deisgn and bump parts
    [Swadge-S2-Devkit.kicad_sch]
2022-04-07 Update with new LCDs
    [Swadge-S2-Devkit.kicad_sch]
2022-04-11 Bump design with new LCDs, etc.
    [Swadge-S2-Devkit.kicad_pcb, Swadge-S2-Devkit.kicad_sch]
2022-04-11 Bump - with bigger outline
    [Swadge-S2-Devkit.kicad_pcb, Swadge-S2-Devkit.kicad_sch]
2022-04-13 Bump with routing
    [Swadge-S2-Devkit.kicad_pcb, Swadge-S2-Devkit.kicad_sch]
2022-04-20 Update as initial rev -
    [Swadge-S2-Devkit.kicad_pcb, Swadge-S2-Devkit.kicad_sch]
2022-05-05 Removed unused parts of schematic. Replaced out of stock parts. Rerouted batteries, LDOs
    [Swadge-S2-Devkit.kicad_pcb, Swadge-S2-Devkit.kicad_sch]
2022-05-05 Fix footprint
    [Swadge-S2-Devkit.kicad_pcb]
2022-05-06 Fixed all import and DRC errors. Cleaned up BOM
    [Swadge-S2-Devkit.kicad_pcb, Swadge-S2-Devkit.kicad_sch]
2022-05-07 Switch inductors, fix warnings
    [Swadge-S2-Devkit.kicad_pcb, Swadge-S2-Devkit.kicad_sch]
2022-05-08 Fixed warnings
    [Swadge-S2-Devkit.kicad_sch]
2022-05-09 Update note for manufacturing Add silkscreen version Ignore output folder
    [Swadge-S2-Devkit.kicad_pcb, Swadge-S2-Devkit.kicad_sch]
2022-07-24 Connect DP2 and DN2 on USB-C connector
    [Swadge-S2-Devkit.kicad_sch]
2022-07-24 Remove accelerometer
    [Swadge-S2-Devkit.kicad_sch]
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2022-07-24 Removed vibration motor
    [Swadge-S2-Devkit.kicad_sch]
2022-07-24 Removed edge and pin connectors
    [Swadge-S2-Devkit.kicad_sch]
2022-07-24 Reduced to six pushbuttons
    [Swadge-S2-Devkit.kicad_sch]
2022-07-24 Fix power schematic
    [Swadge-S2-Devkit.kicad_sch]
2022-07-24 Clean up power schematic
    [Swadge-S2-Devkit.kicad_sch]
2022-07-24 Replaced slide switch
    [Swadge-S2-Devkit.kicad_sch]
2022-07-24 Added new tactile switches
    [Swadge-S2-Devkit.kicad_sch]
2022-07-24 Reset PCB
    [Swadge-S2-Devkit.kicad_pcb]
2022-07-24 Added note for AA holder
    [Swadge-S2-Devkit.kicad_sch]
2022-07-24 Replaced touch wheel with start/select
    [Swadge-S2-Devkit.kicad_pcb, Swadge-S2-Devkit.kicad_sch]
2022-07-27 Updated buttons, LEDs, TFTs for prototype
    [Swadge-S2-Devkit.kicad_pcb, Swadge-S2-Devkit.kicad_sch]
2022-07-28 Started prototype part placement
    [Swadge-S2-Devkit.kicad_pcb, Swadge-S2-Devkit.kicad_sch]
2022-07-29 Added shields projects. Updated main PCB
    [Swadge-S2-Devkit.kicad_pcb, Swadge-S2-Devkit.kicad_sch, shield_l.kicad_pcb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]
2022-07-29 Added LCSC part numbers, cleanup
    [Swadge-S2-Devkit.kicad_pcb, Swadge-S2-Devkit.kicad_sch]
2022-07-29 Fixed footprints and models for mic, bzr, slide switch, SK6812
    [Swadge-S2-Devkit.kicad_pcb, Swadge-S2-Devkit.kicad_sch]
2022-07-29 Added correct FPC connector footprint
    [Swadge-S2-Devkit.kicad_pcb, Swadge-S2-Devkit.kicad_sch]
2022-07-30 Replaced shield_r/l with shield project. Added art files
    [shield_l.kicad_pcb, shield_r.kicad_pcb, shields.kicad_pcb]
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2022-08-02 Cleaned up part references, BOM
    [Swadge-S2-Devkit.kicad_pcb, Swadge-S2-Devkit.kicad_sch]
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2022-08-03 Clean BOM, update designators, move passives from under batteries, flip mic positions, use parts in Swadge_Parts
    [Swadge-S2-Devkit.kicad_sch]
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2022-08-04 Removed 20 pin monstrosity, rerouted
    [Swadge-S2-Devkit.kicad_sch]
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2022-08-05 Moved battery lower. Placed SAO
    [Swadge-S2-Devkit.kicad_sch]
2022-08-05 * Add Slider (remove center touch) * Route board
    [Swadge-S2-Devkit.kicad_sch]
2022-08-05 Forgot to update schematic to reflect change with touch sensor.
    [Swadge-S2-Devkit.kicad_sch]
2022-08-05 Flipped SAO to back, added more battery clearance
2022-08-05 Use C 1210 from Swadge-Parts
    [Swadge-S2-Devkit.kicad_sch]
2022-08-05 Place and route touch bar
    [Swadge-S2-Devkit.kicad_sch]
2022-08-09 fix LCSC part number
    [Swadge-S2-Devkit.kicad_sch]
2022-08-09 Commit from ev1order branch directly to main
    [Swadge-S2-Devkit.kicad_sch]
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2022-08-09 Replaced 4.5mm tact switch with 6mm tact switch, rerouted
    [Swadge-S2-Devkit.kicad_sch]
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2022-08-10 Bump - But it doesn't look like we'll be able to switch the order.
    [Swadge-S2-Devkit.kicad_sch]
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2022-08-24 Add a test SAO
    [SAO1.kicad_pcb, SAO1.kicad_sch]
2022-08-31 Put squarewave art on shields
    [shields.kicad_pcb]
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2022-09-04 Embiggen holes on shield, remove standoff capacitors, tie all standoff pins to GND
    [Swadge-S2-Devkit.kicad_sch, shields.kicad_pcb]
2022-09-04 Flipped, moved, and DNP'd the SAO connector
    [Swadge-S2-Devkit.kicad_sch]
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2022-09-05 Use correct footprint for SAO
    [Swadge-S2-Devkit.kicad_sch]
2022-09-05 Update design to resolve more issues. Notably fixing USB + microphone circuitry and removing designators, and flipping programming header to back-only.
    [Swadge-S2-Devkit.kicad_sch]
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2022-09-05 Tweak export for sheilds
    [shields.kicad_pcb]
2022-09-06 added projects for L&R shields with metal bottoms
    [shield_l.kicad_pcb, shield_r.kicad_pcb]
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2022-09-14 Add metal to sheilds
    [shields.kicad_pcb]
2022-09-22 * Remove 0 ohm resistors (by shorting them through) * Convert 10u to 22u * Fix header LCSC Part # * Add note about nopop on SAO header * Remove dangling 3.3v rail
    [Swadge-S2-Devkit.kicad_sch]
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2022-09-25 Added dpad flourish art
    [Swadge-S2-Devkit.kicad_sch]
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2022-09-26 Resize logos, add to back
    [Swadge-S2-Devkit.kicad_sch]
2022-09-27 Split dpad-flourish into 20th anniv, vertically aligned front logos
    [Swadge-S2-Devkit.kicad_sch]
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2022-10-17 Replace all SK6812D_SIDE footprints with SK6812_SIDE_2 footprints. DID NOT REROUTE. DRC FAILS!
    [Swadge-S2-Devkit.kicad_sch]
2022-10-17 Move to MP2, routing the traces from last commit + Making gerber package + fix gap in track.
2022-10-17 Fix more warnings, clean up more traces
2022-11-09 Add part for shield art
    [shields.kicad_pcb]
2022-11-29 Add 3d prints
    Add 3d print folder, updated readme, uploaded latest STLs for FDM and SLA
    [Eggshell_back_FDM.STL, Eggshell_back_SLA.STL, Eggshell_front_FDM.STL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]
2022-11-30 Update Eggshell_front_FDM
    Deleted offset face
    [Eggshell_front_FDM.STL]
2022-11-30 Revert "Update Eggshell_front_FDM"
    This reverts commit 3d3f6df7c45eaf464af25f82c164def461878c8d.
    [Eggshell_front_FDM.STL]
2022-11-30 repair FDM variant
    deleted offset face
    [Eggshell_back_FDM.STL, Eggshell_front_FDM.STL]
2022-11-30 Update Eggshell_front_FDM.STL
    repair inner faces to make parallel
    [Eggshell_front_FDM.STL]
2022-12-02 Update Eggshell_back_SLA.STL
    changed mounting hole for threaded insert
    [Eggshell_back_SLA.STL]
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
